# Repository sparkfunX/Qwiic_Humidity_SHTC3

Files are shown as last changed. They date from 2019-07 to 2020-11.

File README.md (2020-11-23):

SparkX Qwiic Humidity SHTC3
========================================

Qwiic_Humidity_SHTC3

[*Qwiic Humidity SHTC3*](https://www.sparkfun.com/products/15074)

<Basic description of the part.>

Repository Contents
-------------------

* **/Documentation** - Data sheets, additional product information
* **/Enclosure** - Enclosure files 
* **/Firmware** - Example code 
* **/Hardware** - Eagle design files (.brd, .sch)
* **/Libraries** - Libraries for use with the <PRODUCT NAME>
* **/Production** - Production panel files (.brd)
* **/Software** - Related software for the <PRODUCT NAME>

Documentation
--------------
* **[Arduino Library](https://github.com/sparkfun/SparkFun_SHTC3_Arduino_Library)** - Arduino Library.
* **[Hookup Guide](https://learn.sparkfun.com/tutorials/sparkfun-humidity-sensor-breakout---shtc3-qwiic-hookup-guide)** - Basic hookup guide for the.
* **[SparkFun Fritzing repo](https://github.com/sparkfun/Fritzing_Parts)** - Fritzing diagrams for SparkFun products.
* **[SparkFun 3D Model repo](https://github.com/sparkfun/3D_Models)** - 3D models of SparkFun products. 
* **[SparkFun Graphical Datasheets](https://github.com/sparkfun/Graphical_Datasheets)** -Graphical Datasheets for various SparkFun products.

Product Versions
----------------
* [Part SKU](part URL)- Basic part and short description here
* [Retail part SKU] (retail URL)- Retail packaging of standard description here
* [Any other parts this repo covers](any other URLs) - Description of said parts

Version History
---------------
* [vExxFxxZxxHxxLxxSxx](URL for tag specific to this version) - Description 
* [vEyyFyyZyyHyyLyySyy](URL for tag specific to this version) - Description

License Information
-------------------

This product is _**open source**_! 

Please review the LICENSE.md file for license information. 

If you have any questions or concerns on licensing, please contact techsupport@sparkfun.com.

Distributed as-is; no warranty is given.

- Your friends at SparkFun.

_<COLLABORATION CREDIT>_

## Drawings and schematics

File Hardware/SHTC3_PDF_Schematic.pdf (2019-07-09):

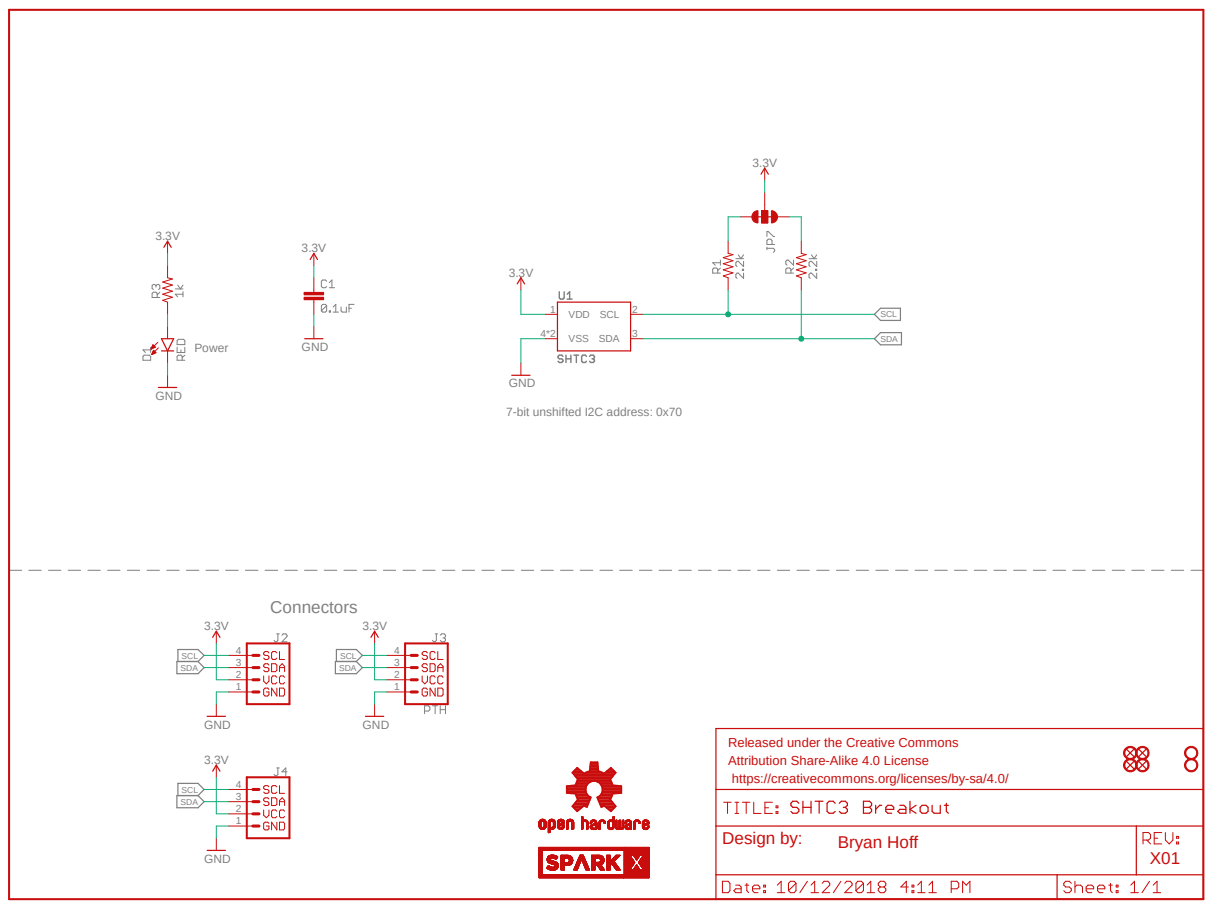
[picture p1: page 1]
Power; Connectors; GND; VDD 1; SCL 2 VSS 4*2; SDA 3; SCL; SCL SCL; SDA; Bryan Hoff; Design by:

7-bit unshifted I2C address: 0x70

Released under the Creative Commons
Attribution Share-Alike 4.0 License
https://creativecommons.org/licenses/by-sa/4.0/

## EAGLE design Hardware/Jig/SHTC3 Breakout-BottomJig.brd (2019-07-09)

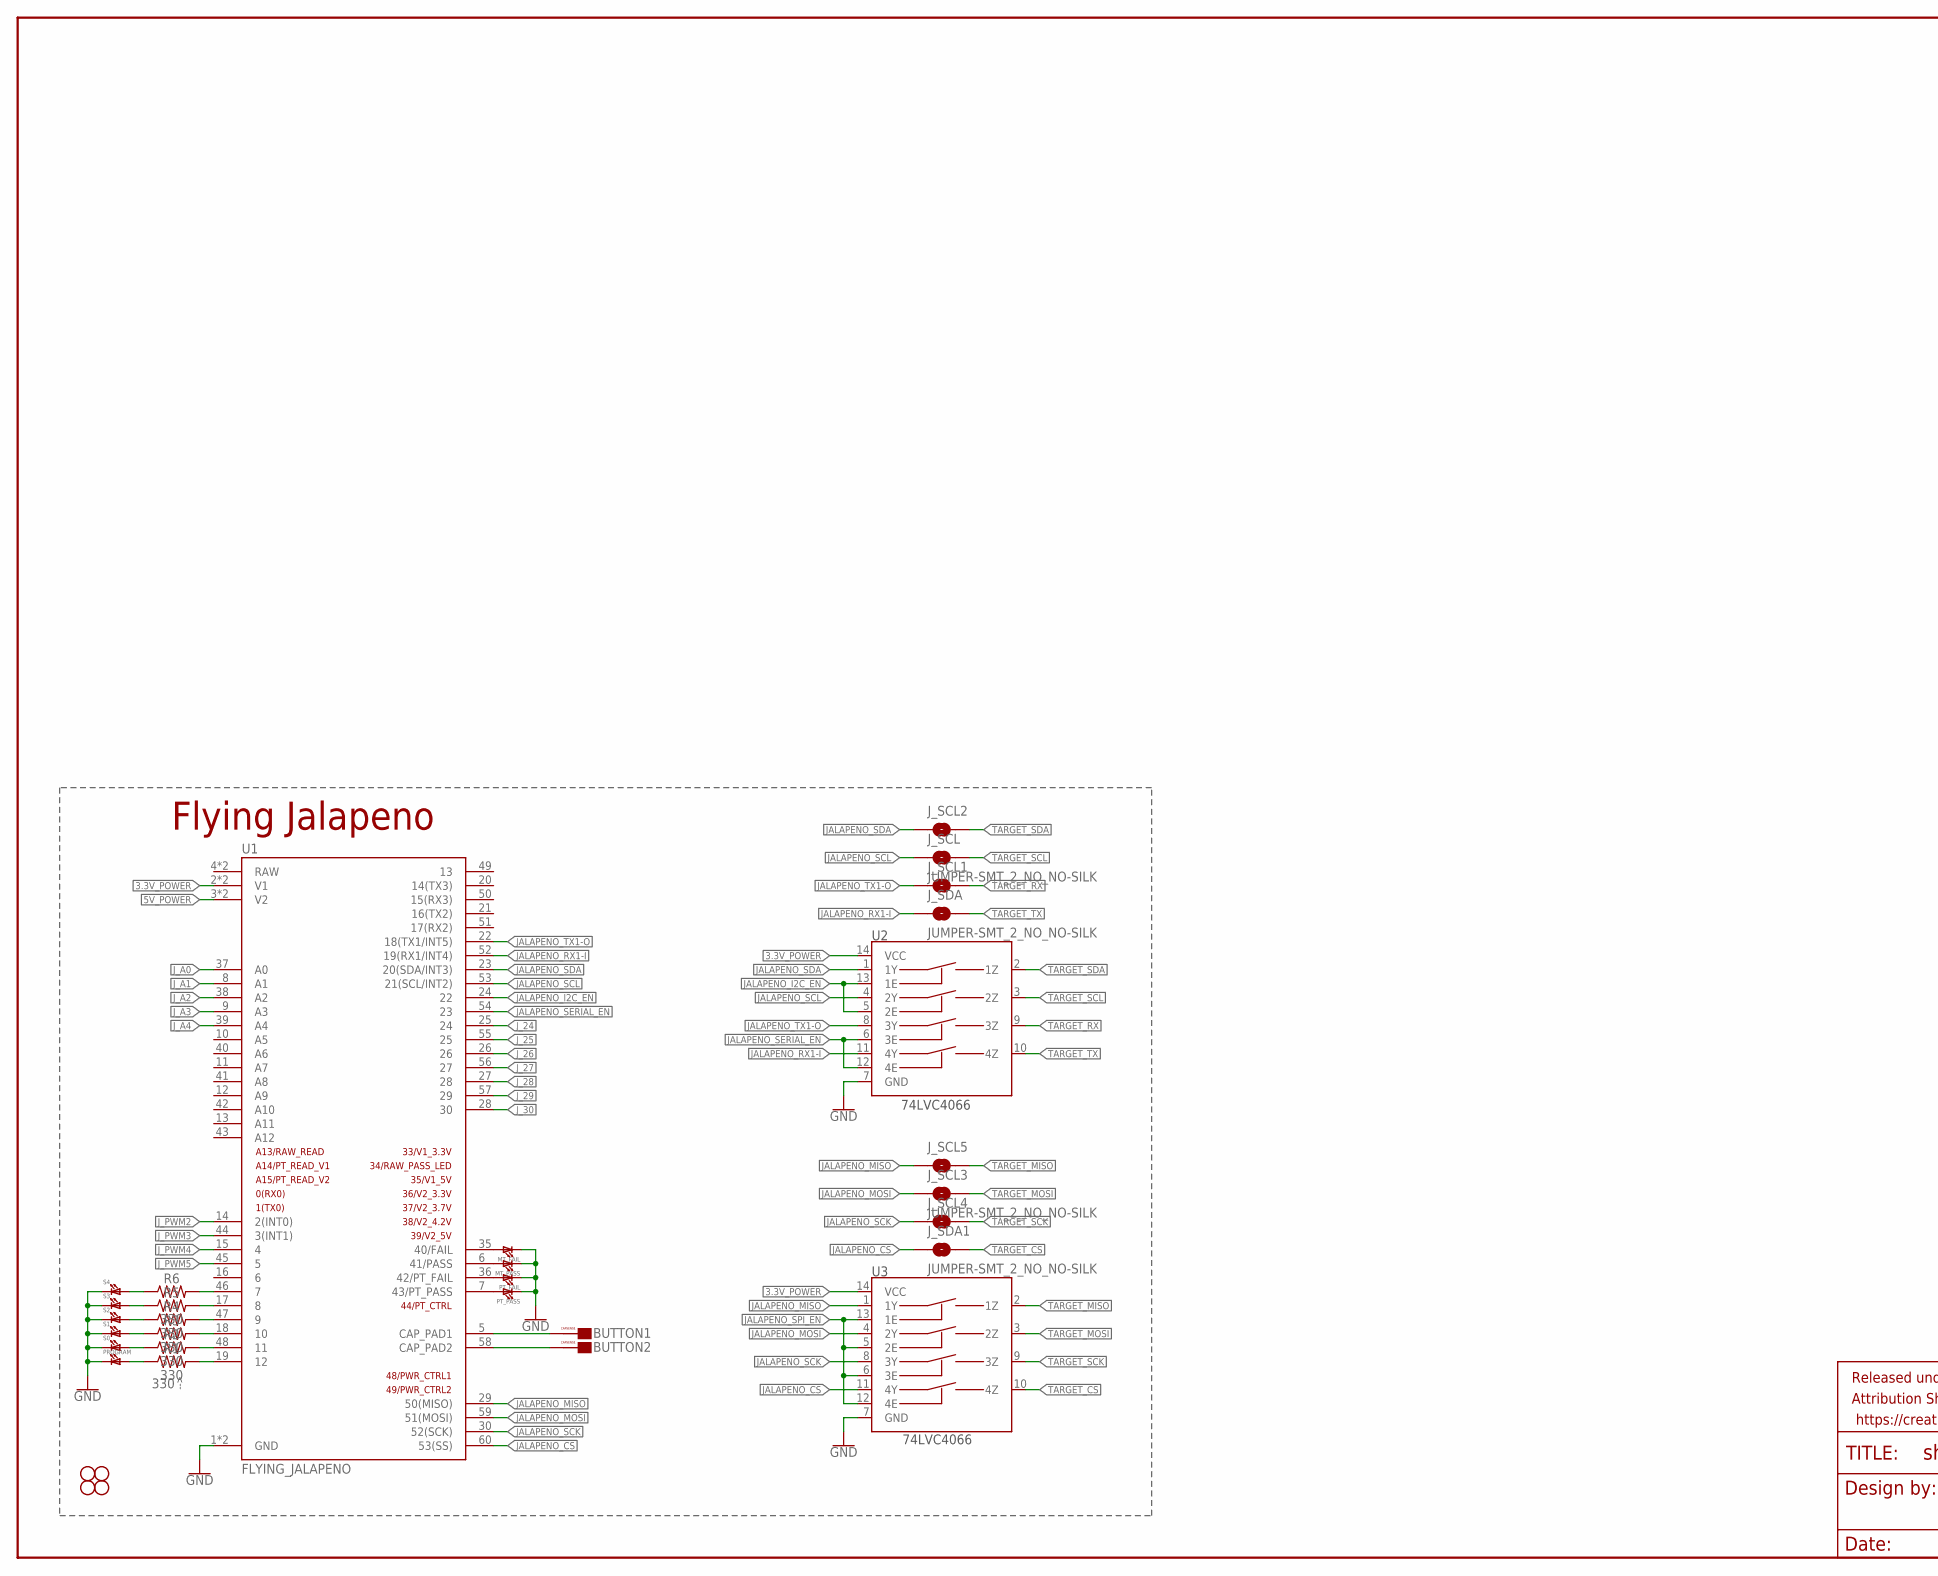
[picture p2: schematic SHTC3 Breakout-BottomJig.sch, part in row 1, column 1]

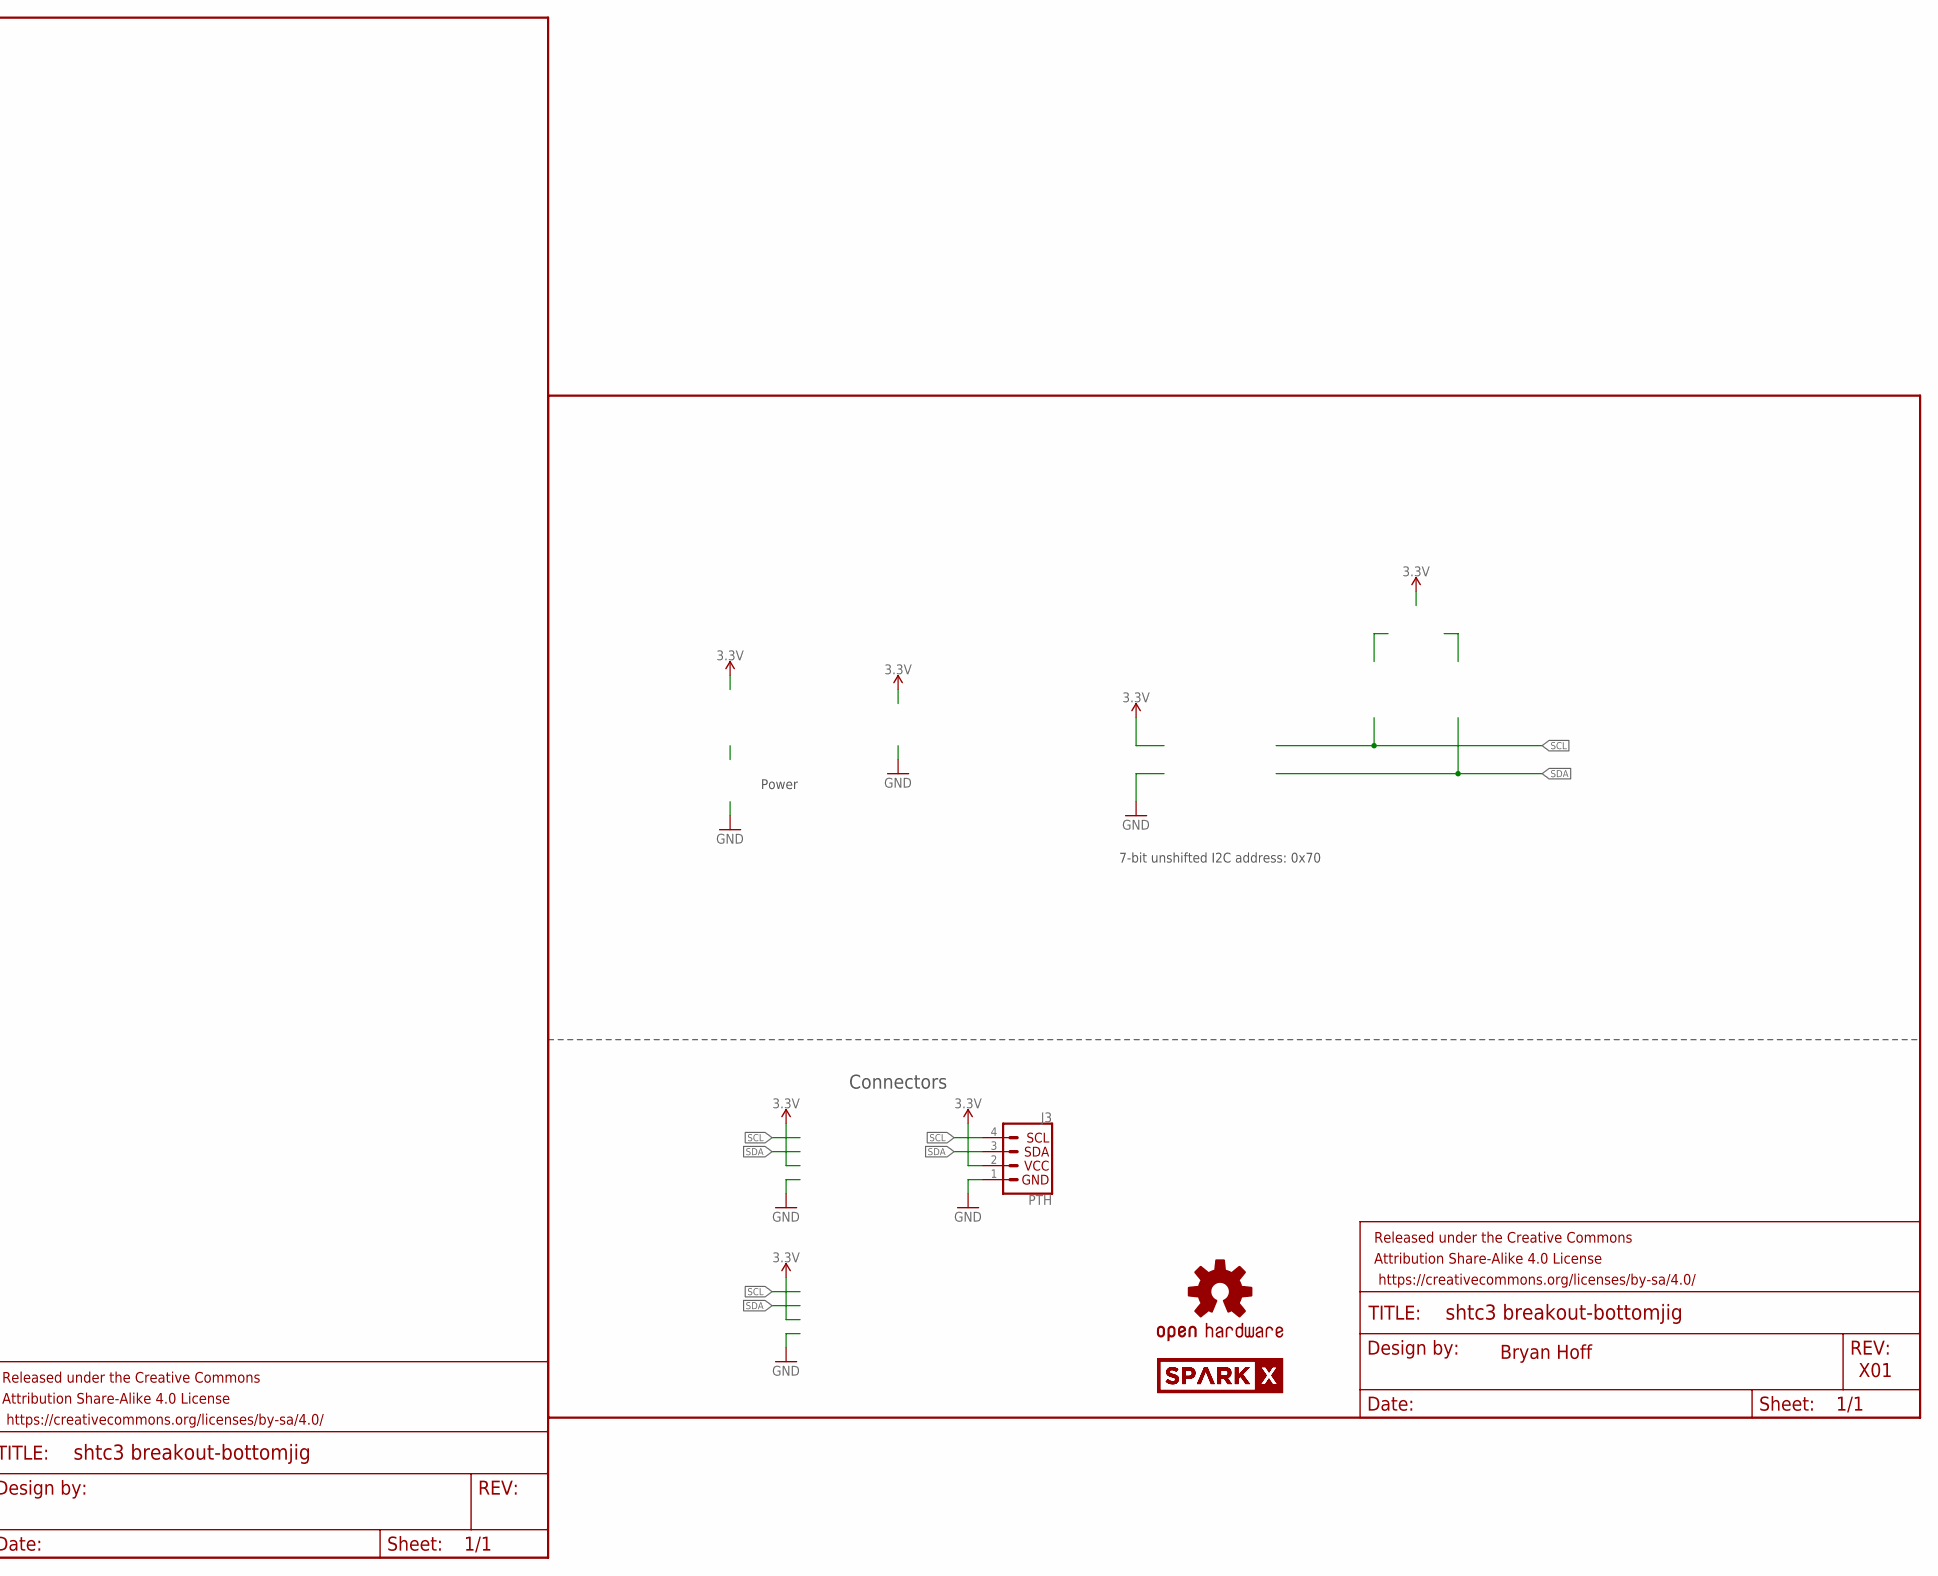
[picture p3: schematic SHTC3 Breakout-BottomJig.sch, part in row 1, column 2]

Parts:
BUTTON1, BUTTON2: CAPSENSE_BUTTON_PAD_ONLY; CAPSENSE_BUTTON_PADS_ONLY
FRAME1: FRAME-LETTER; CREATIVE_COMMONS
FRAME2: FRAME-LEDGER; CREATIVE_COMMONS
H1, H2, H3, H4: STAND-OFF
J3: PTH; 1X04_NO_SILK
J_SCL, J_SCL1, J_SCL2, J_SCL3, J_SCL4, J_SCL5: JUMPER-SMT_2_NO_NO-SILK; SMT-JUMPER_2_NO_NO-SILK
J_SDA, J_SDA1: JUMPER-SMT_2_NO_NO-SILK; SMT-JUMPER_2_NO_NO-SILK
LOGO1: OSHW-LOGOMINI; OSHW-LOGO-MINI
MT_FAIL: LED1206; LED-1206
MT_PASS: LED1206; LED-1206
PROGRAM: LED1206; LED-1206
PT_FAIL: LED1206; LED-1206
PT_PASS: LED1206; LED-1206
R1, R2, R3, R4, R5, R6: 330; 0603
S0, S1, S2, S3, S4: LED1206; LED-1206
U1: FLYING_JALAPENO; FLYING_JALAPENO_V3_M
U2, U3: 74LVC4066; SO14
U$1, U$2: SPARKX-LOGO4; SPARKX-MEDIUM

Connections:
3.3V: J3.2 (VCC)
3.3V_POWER: U1.2 (V1), U1.32 (V1), U2.14 (VCC), U3.14 (VCC)
5V_POWER: U1.3 (V2), U1.33 (V2)
GND: J3.1 (GND), MT_FAIL.C, MT_PASS.C, PROGRAM.C, PT_FAIL.C, PT_PASS.C, S0.C, S1.C, S2.C, S3.C, S4.C, U1.1 (GND), U1.31 (GND), U2.7 (GND), U3.7 (GND)
JALAPENO_CS: J_SDA1.1, U1.60 (53(SS)), U3.11 (4Y)
JALAPENO_I2C_EN: U1.24 (22), U2.5 (2E), U2.13 (1E)
JALAPENO_MISO: J_SCL5.1, U1.29 (50(MISO)), U3.1 (1Y)
JALAPENO_MOSI: J_SCL3.1, U1.59 (51(MOSI)), U3.4 (2Y)
JALAPENO_RX1-I: J_SDA.1, U1.52 (19(RX1/INT4)), U2.11 (4Y)
JALAPENO_SCK: J_SCL4.1, U1.30 (52(SCK)), U3.8 (3Y)
JALAPENO_SCL: J_SCL.1, U1.53 (21(SCL/INT2)), U2.4 (2Y)
JALAPENO_SDA: J_SCL2.1, U1.23 (20(SDA/INT3)), U2.1 (1Y)
JALAPENO_SERIAL_EN: U1.54 (23), U2.6 (3E), U2.12 (4E)
JALAPENO_SPI_EN: U3.5 (2E), U3.6 (3E), U3.12 (4E), U3.13 (1E)
JALAPENO_TX1-O: J_SCL1.1, U1.22 (18(TX1/INT5)), U2.8 (3Y)
J_24: U1.25 (24)
J_25: U1.55 (25)
J_26: U1.26
J_27: U1.56 (27)
J_28: U1.27 (28)
J_29: U1.57 (29)
J_30: U1.28 (30)
J_A0: U1.37 (A0)
J_A1: U1.8 (A1)
J_A2: U1.38 (A2)
J_A3: U1.9 (A3)
J_A4: U1.39 (A4)
J_PWM2: U1.14 (2(INT0))
J_PWM3: U1.44 (3(INT1))
J_PWM4: U1.15 (4)
J_PWM5: U1.45 (5)
unnamed: PT_PASS.A, U1.7 (43/PT_PASS)
unnamed: PT_FAIL.A, U1.36 (42/PT_FAIL)
unnamed: MT_PASS.A, U1.6 (41/PASS)
unnamed: MT_FAIL.A, U1.35 (40/FAIL)
unnamed: BUTTON2.CAPSENSE_PAD, U1.58 (CAP_PAD2)
unnamed: BUTTON1.CAPSENSE_PAD, U1.5 (CAP_PAD1)
unnamed: R6.2, U1.46 (7)
unnamed: R1.2, U1.19 (12)
unnamed: PROGRAM.A, R1.1
unnamed: R5.2, U1.17 (8)
unnamed: R4.2, U1.47 (9)
unnamed: R3.2, U1.18 (10)
unnamed: R2.2, U1.48 (11)
unnamed: R6.1, S4.A
unnamed: R5.1, S3.A
unnamed: R4.1, S2.A
unnamed: R3.1, S1.A
unnamed: R2.1, S0.A
SCL: J3.4 (SCL)
SDA: J3.3 (SDA)
TARGET_CS: J_SDA1.2, U3.10 (4Z)
TARGET_MISO: J_SCL5.2, U3.2 (1Z)
TARGET_MOSI: J_SCL3.2, U3.3 (2Z)
TARGET_RX: J_SCL1.2, U2.9 (3Z)
TARGET_SCK: J_SCL4.2, U3.9 (3Z)
TARGET_SCL: J_SCL.2, U2.3 (2Z)
TARGET_SDA: J_SCL2.2, U2.2 (1Z)
TARGET_TX: J_SDA.2, U2.10 (4Z)

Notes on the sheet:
Bryan Hoff
X01
7-bit unshifted I2C address: 0x70
Power
Connectors
Flying Jalapeno
-->

Board: 2 copper layers, 58 parts (9 on the bottom side), 40 nets, no tracks yet.

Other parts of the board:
U$3, U$22: GND1
U$4, U$21: 3#3V2
U$5, U$27: SDA8
U$6, U$26: SCL9
U$7, U$8: SHTC3_HUMIDITY1
U$9: I_SUPER2_C-()-03
U$10: (PWR)
U$11, U$12, U$13, U$14, U$15, U$16: STAND-OFF-TIGHT
U$29: QWIIC-LOGO-MEDIUM

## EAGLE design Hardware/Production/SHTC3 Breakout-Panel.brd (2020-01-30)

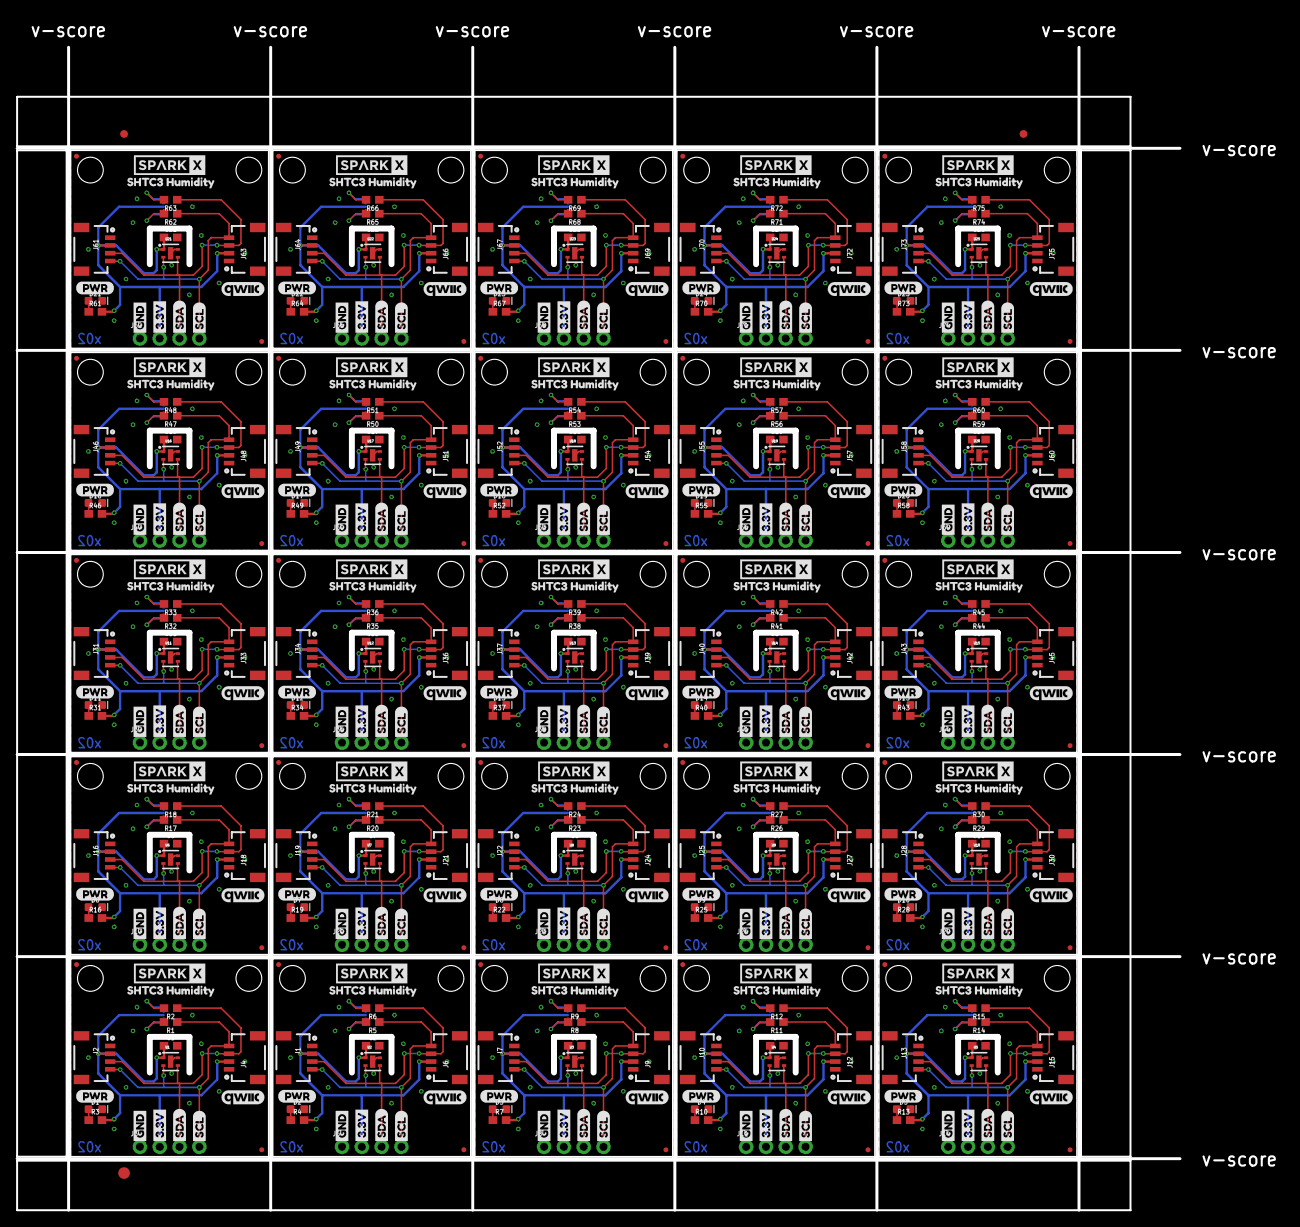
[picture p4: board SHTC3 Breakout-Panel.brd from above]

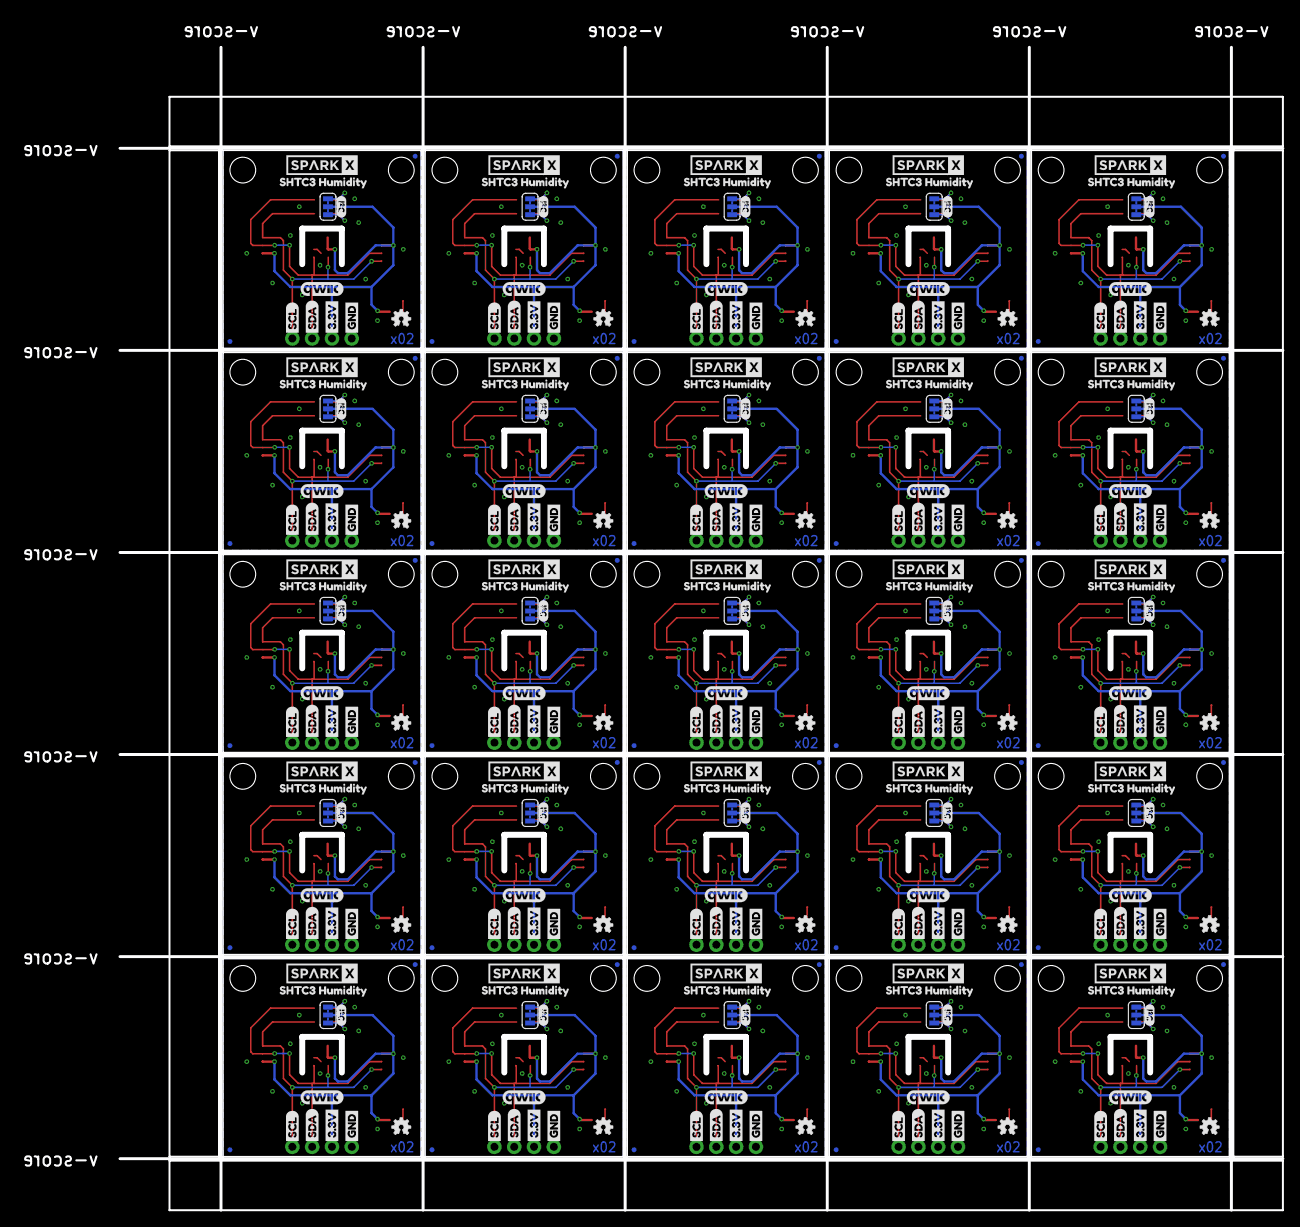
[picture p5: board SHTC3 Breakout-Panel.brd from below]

Board: 2 copper layers, 149.1 x 149.1 mm, 828 parts (300 on the bottom side), 175 nets.

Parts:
C1, C2, C3, C4, C5, C6, C7, C8, C9, C10, C11, C12, C13, C14, C15, C16, C17, C18, C19, C20, C21, C22, C23, C24, C25: 0.1uF; 0603
D1, D2, D3, D4, D5, D6, D7, D8, D9, D10, D11, D12, D13, D14, D15, D16, D17, D18, D19, D20, D21, D22, D23, D24, D25: RED; LED-0603
E$1, E$2: FIDUCIAL-1X2
E$3: FIDUCIAL-1.5X3
J1, J2, J4, J6, J7, J9, J10, J12, J13, J15, J16, J18, J19, J21, J22, J24, J25, J27, J28, J30, J31, J33, J34, J36, J37, J39, J40, J42, J43, J45, J46, J48, J49, J51, J52, J54, J55, J57, J58, J60, J61, J63, J64, J66, J67, J69, J70, J72, J73, J75: 1X04_1MM_RA
J3, J5, J8, J11, J14, J17, J20, J23, J26, J29, J32, J35, J38, J41, J44, J47, J50, J53, J56, J59, J62, J65, J68, J71, J74: PTH; 1X04_NO_SILK
JP1, JP2, JP5, JP6, JP10, JP11, JP12, JP13, JP17, JP18, JP19, JP20, JP24, JP25, JP26, JP27, JP31, JP32, JP33, JP34, JP38, JP39, JP40, JP41, JP45, JP46, JP47, JP48, JP52, JP53, JP54, JP55, JP59, JP60, JP61, JP62, JP66, JP67, JP68, JP69, JP73, JP74, JP75, JP76, JP80, JP81, JP82, JP83, JP87, JP88, JP89, JP90, JP94, JP95, JP96, JP97, JP101, JP102, JP103, JP104, JP108, JP109, JP110, JP111, JP115, JP116, JP117, JP118, JP122, JP123, JP124, JP125, JP129, JP130, JP131, JP132, JP136, JP137, JP138, JP139, JP143, JP144, JP145, JP146, JP150, JP151, JP152, JP153, JP157, JP158, JP159, JP160, JP164, JP165, JP166, JP167, JP171, JP172, JP173, JP174: FIDUCIALUFIDUCIAL; MICRO-FIDUCIAL
JP3, JP4, JP8, JP9, JP15, JP16, JP22, JP23, JP29, JP30, JP36, JP37, JP43, JP44, JP50, JP51, JP57, JP58, JP64, JP65, JP71, JP72, JP78, JP79, JP85, JP86, JP92, JP93, JP99, JP100, JP106, JP107, JP113, JP114, JP120, JP121, JP127, JP128, JP134, JP135, JP141, JP142, JP148, JP149, JP155, JP156, JP162, JP163, JP169, JP170: STAND-OFF
JP7, JP14, JP21, JP28, JP35, JP42, JP49, JP56, JP63, JP70, JP77, JP84, JP91, JP98, JP105, JP112, JP119, JP126, JP133, JP140, JP147, JP154, JP161, JP168, JP175: JUMPER-SMT_3_2-NC_TRACE_SILK; SMT-JUMPER_3_2-NC_TRACE_SILK
LOGO1, LOGO2, LOGO3, LOGO4, LOGO5, LOGO6, LOGO7, LOGO8, LOGO9, LOGO10, LOGO11, LOGO12, LOGO13, LOGO14, LOGO15, LOGO16, LOGO17, LOGO18, LOGO19, LOGO20, LOGO21, LOGO22, LOGO23, LOGO24, LOGO25: OSHW-LOGOMINI; OSHW-LOGO-MINI
R1, R2, R5, R6, R8, R9, R11, R12, R14, R15, R17, R18, R20, R21, R23, R24, R26, R27, R29, R30, R32, R33, R35, R36, R38, R39, R41, R42, R44, R45, R47, R48, R50, R51, R53, R54, R56, R57, R59, R60, R62, R63, R65, R66, R68, R69, R71, R72, R74, R75: 2.2k; 0603
R3, R4, R7, R10, R13, R16, R19, R22, R25, R28, R31, R34, R37, R40, R43, R46, R49, R52, R55, R58, R61, R64, R67, R70, R73: 1k; 0603
U1, U2, U3, U4, U5, U6, U7, U8, U9, U10, U11, U12, U13, U14, U15, U16, U17, U18, U19, U20, U21, U22, U23, U24, U25: SHTC3
U$1, U$2, U$13, U$14, U$33, U$34, U$49, U$50, U$65, U$66, U$81, U$82, U$97, U$98, U$113, U$114, U$129, U$130, U$145, U$146, U$161, U$162, U$177, U$178, U$193, U$194, U$209, U$210, U$225, U$226, U$241, U$242, U$257, U$258, U$273, U$274, U$289, U$290, U$305, U$306, U$321, U$322, U$337, U$338, U$353, U$354, U$369, U$370, U$385, U$386: SPARKX-LOGO4; SPARKX-MEDIUM
U$3, U$16, U$19, U$22, U$36, U$39, U$52, U$55, U$68, U$71, U$84, U$87, U$100, U$103, U$116, U$119, U$132, U$135, U$148, U$151, U$164, U$167, U$180, U$183, U$196, U$199, U$212, U$215, U$228, U$231, U$244, U$247, U$260, U$263, U$276, U$279, U$292, U$295, U$308, U$311, U$324, U$327, U$340, U$343, U$356, U$359, U$372, U$375, U$388, U$391: GND1
U$4, U$15, U$20, U$21, U$35, U$40, U$51, U$56, U$67, U$72, U$83, U$88, U$99, U$104, U$115, U$120, U$131, U$136, U$147, U$152, U$163, U$168, U$179, U$184, U$195, U$200, U$211, U$216, U$227, U$232, U$243, U$248, U$259, U$264, U$275, U$280, U$291, U$296, U$307, U$312, U$323, U$328, U$339, U$344, U$355, U$360, U$371, U$376, U$387, U$392: 3#3V2
U$5, U$18, U$23, U$27, U$38, U$41, U$54, U$57, U$70, U$73, U$86, U$89, U$102, U$105, U$118, U$121, U$134, U$137, U$150, U$153, U$166, U$169, U$182, U$185, U$198, U$201, U$214, U$217, U$230, U$233, U$246, U$249, U$262, U$265, U$278, U$281, U$294, U$297, U$310, U$313, U$326, U$329, U$342, U$345, U$358, U$361, U$374, U$377, U$390, U$393: SDA8
U$6, U$17, U$24, U$26, U$37, U$42, U$53, U$58, U$69, U$74, U$85, U$90, U$101, U$106, U$117, U$122, U$133, U$138, U$149, U$154, U$165, U$170, U$181, U$186, U$197, U$202, U$213, U$218, U$229, U$234, U$245, U$250, U$261, U$266, U$277, U$282, U$293, U$298, U$309, U$314, U$325, U$330, U$341, U$346, U$357, U$362, U$373, U$378, U$389, U$394: SCL9
U$7, U$8, U$28, U$29, U$44, U$45, U$60, U$61, U$76, U$77, U$92, U$93, U$108, U$109, U$124, U$125, U$140, U$141, U$156, U$157, U$172, U$173, U$188, U$189, U$204, U$205, U$220, U$221, U$236, U$237, U$252, U$253, U$268, U$269, U$284, U$285, U$300, U$301, U$316, U$317, U$332, U$333, U$348, U$349, U$364, U$365, U$380, U$381, U$396, U$397: SHTC3_HUMIDITY1
U$9, U$30, U$46, U$62, U$78, U$94, U$110, U$126, U$142, U$158, U$174, U$190, U$206, U$222, U$238, U$254, U$270, U$286, U$302, U$318, U$334, U$350, U$366, U$382, U$398: I_SUPER2_C-()-03
U$10, U$25, U$43, U$59, U$75, U$91, U$107, U$123, U$139, U$155, U$171, U$187, U$203, U$219, U$235, U$251, U$267, U$283, U$299, U$315, U$331, U$347, U$363, U$379, U$395: (PWR)
U$11, U$12, U$31, U$32, U$47, U$48, U$63, U$64, U$79, U$80, U$95, U$96, U$111, U$112, U$127, U$128, U$143, U$144, U$159, U$160, U$175, U$176, U$191, U$192, U$207, U$208, U$223, U$224, U$239, U$240, U$255, U$256, U$271, U$272, U$287, U$288, U$303, U$304, U$319, U$320, U$335, U$336, U$351, U$352, U$367, U$368, U$383, U$384, U$399, U$400: QWIIC_5.5MM

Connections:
3.3V: C1.1, J2.2, J3.2, J4.2, JP7.2, R3.2, U1.1
3.3V1: C2.1, J1.2, J5.2, J6.2, JP14.2, R4.2, U2.1
3.3V2: C3.1, J7.2, J8.2, J9.2, JP21.2, R7.2, U3.1
3.3V3: C4.1, J10.2, J11.2, J12.2, JP28.2, R10.2, U4.1
3.3V4: C5.1, J13.2, J14.2, J15.2, JP35.2, R13.2, U5.1
3.3V5: C6.1, J16.2, J17.2, J18.2, JP42.2, R16.2, U6.1
3.3V6: C7.1, J19.2, J20.2, J21.2, JP49.2, R19.2, U7.1
3.3V7: C8.1, J22.2, J23.2, J24.2, JP56.2, R22.2, U8.1
3.3V8: C9.1, J25.2, J26.2, J27.2, JP63.2, R25.2, U9.1
3.3V9: C10.1, J28.2, J29.2, J30.2, JP70.2, R28.2, U10.1
3.3V10: C11.1, J31.2, J32.2, J33.2, JP77.2, R31.2, U11.1
3.3V11: C12.1, J34.2, J35.2, J36.2, JP84.2, R34.2, U12.1
3.3V12: C13.1, J37.2, J38.2, J39.2, JP91.2, R37.2, U13.1
3.3V13: C14.1, J40.2, J41.2, J42.2, JP98.2, R40.2, U14.1
3.3V14: C15.1, J43.2, J44.2, J45.2, JP105.2, R43.2, U15.1
3.3V15: C16.1, J46.2, J47.2, J48.2, JP112.2, R46.2, U16.1
3.3V16: C17.1, J49.2, J50.2, J51.2, JP119.2, R49.2, U17.1
3.3V17: C18.1, J52.2, J53.2, J54.2, JP126.2, R52.2, U18.1
3.3V18: C19.1, J55.2, J56.2, J57.2, JP133.2, R55.2, U19.1
3.3V19: C20.1, J58.2, J59.2, J60.2, JP140.2, R58.2, U20.1
3.3V20: C21.1, J61.2, J62.2, J63.2, JP147.2, R61.2, U21.1
3.3V21: C22.1, J64.2, J65.2, J66.2, JP154.2, R64.2, U22.1
3.3V22: C23.1, J67.2, J68.2, J69.2, JP161.2, R67.2, U23.1
3.3V23: C24.1, J70.2, J71.2, J72.2, JP168.2, R70.2, U24.1
3.3V24: C25.1, J73.2, J74.2, J75.2, JP175.2, R73.2, U25.1
GND: C1.2, D1.C, J2.1, J3.1, J4.1, U1.4, U1.5
GND1: C2.2, D2.C, J1.1, J5.1, J6.1, U2.4, U2.5
GND2: C3.2, D3.C, J7.1, J8.1, J9.1, U3.4, U3.5
GND3: C4.2, D4.C, J10.1, J11.1, J12.1, U4.4, U4.5
GND4: C5.2, D5.C, J13.1, J14.1, J15.1, U5.4, U5.5
GND5: C6.2, D6.C, J16.1, J17.1, J18.1, U6.4, U6.5
GND6: C7.2, D7.C, J19.1, J20.1, J21.1, U7.4, U7.5
GND7: C8.2, D8.C, J22.1, J23.1, J24.1, U8.4, U8.5
GND8: C9.2, D9.C, J25.1, J26.1, J27.1, U9.4, U9.5
GND9: C10.2, D10.C, J28.1, J29.1, J30.1, U10.4, U10.5
GND10: C11.2, D11.C, J31.1, J32.1, J33.1, U11.4, U11.5
GND11: C12.2, D12.C, J34.1, J35.1, J36.1, U12.4, U12.5
GND12: C13.2, D13.C, J37.1, J38.1, J39.1, U13.4, U13.5
GND13: C14.2, D14.C, J40.1, J41.1, J42.1, U14.4, U14.5
GND14: C15.2, D15.C, J43.1, J44.1, J45.1, U15.4, U15.5
GND15: C16.2, D16.C, J46.1, J47.1, J48.1, U16.4, U16.5
GND16: C17.2, D17.C, J49.1, J50.1, J51.1, U17.4, U17.5
GND17: C18.2, D18.C, J52.1, J53.1, J54.1, U18.4, U18.5
GND18: C19.2, D19.C, J55.1, J56.1, J57.1, U19.4, U19.5
GND19: C20.2, D20.C, J58.1, J59.1, J60.1, U20.4, U20.5
GND20: C21.2, D21.C, J61.1, J62.1, J63.1, U21.4, U21.5
GND21: C22.2, D22.C, J64.1, J65.1, J66.1, U22.4, U22.5
GND22: C23.2, D23.C, J67.1, J68.1, J69.1, U23.4, U23.5
GND23: C24.2, D24.C, J70.1, J71.1, J72.1, U24.4, U24.5
GND24: C25.2, D25.C, J73.1, J74.1, J75.1, U25.4, U25.5
unnamed: JP7.3, R1.2
unnamed: JP7.1, R2.2
unnamed: D1.A, R3.1
unnamed: D2.A, R4.1
unnamed: JP14.3, R5.2
unnamed: JP14.1, R6.2
unnamed: D3.A, R7.1
unnamed: JP21.3, R8.2
unnamed: JP21.1, R9.2
unnamed: D4.A, R10.1
unnamed: JP28.3, R11.2
unnamed: JP28.1, R12.2
unnamed: D5.A, R13.1
unnamed: JP35.3, R14.2
unnamed: JP35.1, R15.2
unnamed: D6.A, R16.1
unnamed: JP42.3, R17.2
unnamed: JP42.1, R18.2
unnamed: D7.A, R19.1
unnamed: JP49.3, R20.2
unnamed: JP49.1, R21.2
unnamed: D8.A, R22.1
unnamed: JP56.3, R23.2
unnamed: JP56.1, R24.2
unnamed: D9.A, R25.1
unnamed: JP63.3, R26.2
unnamed: JP63.1, R27.2
unnamed: D10.A, R28.1
unnamed: JP70.3, R29.2
unnamed: JP70.1, R30.2
unnamed: D11.A, R31.1
unnamed: JP77.3, R32.2
unnamed: JP77.1, R33.2
unnamed: D12.A, R34.1
unnamed: JP84.3, R35.2
unnamed: JP84.1, R36.2
unnamed: D13.A, R37.1
unnamed: JP91.3, R38.2
unnamed: JP91.1, R39.2
unnamed: D14.A, R40.1
unnamed: JP98.3, R41.2
unnamed: JP98.1, R42.2
unnamed: D15.A, R43.1
unnamed: JP105.3, R44.2
unnamed: JP105.1, R45.2
unnamed: D16.A, R46.1
unnamed: JP112.3, R47.2
unnamed: JP112.1, R48.2
unnamed: D17.A, R49.1
unnamed: JP119.3, R50.2
unnamed: JP119.1, R51.2
unnamed: D18.A, R52.1
unnamed: JP126.3, R53.2
unnamed: JP126.1, R54.2
unnamed: D19.A, R55.1
unnamed: JP133.3, R56.2
unnamed: JP133.1, R57.2
unnamed: D20.A, R58.1
unnamed: JP140.3, R59.2
unnamed: JP140.1, R60.2
unnamed: D21.A, R61.1
unnamed: JP147.3, R62.2
unnamed: JP147.1, R63.2
unnamed: D22.A, R64.1
unnamed: JP154.3, R65.2
unnamed: JP154.1, R66.2
unnamed: D23.A, R67.1
unnamed: JP161.3, R68.2
unnamed: JP161.1, R69.2
unnamed: D24.A, R70.1
unnamed: JP168.3, R71.2
unnamed: JP168.1, R72.2
unnamed: D25.A, R73.1
unnamed: JP175.3, R74.2
unnamed: JP175.1, R75.2
SCL: J2.4, J3.4, J4.4, R1.1, U1.2
SCL1: J1.4, J5.4, J6.4, R5.1, U2.2
SCL2: J7.4, J8.4, J9.4, R8.1, U3.2
SCL3: J10.4, J11.4, J12.4, R11.1, U4.2
SCL4: J13.4, J14.4, J15.4, R14.1, U5.2
SCL5: J16.4, J17.4, J18.4, R17.1, U6.2
SCL6: J19.4, J20.4, J21.4, R20.1, U7.2
SCL7: J22.4, J23.4, J24.4, R23.1, U8.2
SCL8: J25.4, J26.4, J27.4, R26.1, U9.2
SCL9: J28.4, J29.4, J30.4, R29.1, U10.2
SCL10: J31.4, J32.4, J33.4, R32.1, U11.2
SCL11: J34.4, J35.4, J36.4, R35.1, U12.2
SCL12: J37.4, J38.4, J39.4, R38.1, U13.2
SCL13: J40.4, J41.4, J42.4, R41.1, U14.2
SCL14: J43.4, J44.4, J45.4, R44.1, U15.2
SCL15: J46.4, J47.4, J48.4, R47.1, U16.2
SCL16: J49.4, J50.4, J51.4, R50.1, U17.2
SCL17: J52.4, J53.4, J54.4, R53.1, U18.2
SCL18: J55.4, J56.4, J57.4, R56.1, U19.2
SCL19: J58.4, J59.4, J60.4, R59.1, U20.2
SCL20: J61.4, J62.4, J63.4, R62.1, U21.2
SCL21: J64.4, J65.4, J66.4, R65.1, U22.2
SCL22: J67.4, J68.4, J69.4, R68.1, U23.2
SCL23: J70.4, J71.4, J72.4, R71.1, U24.2
SCL24: J73.4, J74.4, J75.4, R74.1, U25.2
SDA: J2.3, J3.3, J4.3, R2.1, U1.3
SDA1: J1.3, J5.3, J6.3, R6.1, U2.3
SDA2: J7.3, J8.3, J9.3, R9.1, U3.3
SDA3: J10.3, J11.3, J12.3, R12.1, U4.3
SDA4: J13.3, J14.3, J15.3, R15.1, U5.3
SDA5: J16.3, J17.3, J18.3, R18.1, U6.3
SDA6: J19.3, J20.3, J21.3, R21.1, U7.3
SDA7: J22.3, J23.3, J24.3, R24.1, U8.3
SDA8: J25.3, J26.3, J27.3, R27.1, U9.3
SDA9: J28.3, J29.3, J30.3, R30.1, U10.3
SDA10: J31.3, J32.3, J33.3, R33.1, U11.3
SDA11: J34.3, J35.3, J36.3, R36.1, U12.3
SDA12: J37.3, J38.3, J39.3, R39.1, U13.3
SDA13: J40.3, J41.3, J42.3, R42.1, U14.3
SDA14: J43.3, J44.3, J45.3, R45.1, U15.3
SDA15: J46.3, J47.3, J48.3, R48.1, U16.3
SDA16: J49.3, J50.3, J51.3, R51.1, U17.3
SDA17: J52.3, J53.3, J54.3, R54.1, U18.3
SDA18: J55.3, J56.3, J57.3, R57.1, U19.3
SDA19: J58.3, J59.3, J60.3, R60.1, U20.3
SDA20: J61.3, J62.3, J63.3, R63.1, U21.3
SDA21: J64.3, J65.3, J66.3, R66.1, U22.3
SDA22: J67.3, J68.3, J69.3, R69.1, U23.3
SDA23: J70.3, J71.3, J72.3, R72.1, U24.3
SDA24: J73.3, J74.3, J75.3, R75.1, U25.3

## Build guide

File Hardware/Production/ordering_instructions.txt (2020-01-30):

panel size, 143x143mm
PCB thickness, 1.6mm
number of layers, 2
soldermask color, Black
silkscreen color, White
oz copper, 1oz
finish, HASL lead free
stencils, top+bottom
pcs per panel, 25
min trace width, 0.2032mm / 0.0080in
min drill size, 0.3048mm / 0.0120in

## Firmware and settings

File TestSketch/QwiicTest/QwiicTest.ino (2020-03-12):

/*

*/

#include "SparkFun_SHTC3.h" // Click here to get the library: http://librarymanager/All#SparkFun_SHTC3

SHTC3 mySHTC3;

const byte statLED = 13;

void setup() {
  Serial.begin(115200);
  Serial.println("SHTC3 Tester");

  pinMode(statLED, OUTPUT);
  digitalWrite(statLED, LOW);
}

void loop() {
  if (mySHTC3.begin() == SHTC3_Status_Nominal)
  {
    while (mySHTC3.lastStatus == SHTC3_Status_Nominal)
    {
      mySHTC3.update();
      Serial.print("RH = ");
      Serial.print(mySHTC3.toPercent());
      Serial.println();

      if(mySHTC3.toPercent() > 1.0 && mySHTC3.toPercent() < 99.0)
      {
        digitalWrite(statLED, HIGH); //Indicate good board        
      }

      delay(50);
    }
  }
  else
  {
    Serial.println("No sensor detected");
    digitalWrite(statLED, LOW);
  }

  delay(100);
}

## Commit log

2018-10-11 Initial Commit
    SHTC3 Sensor
2018-10-11 Created PCB footprint
2018-10-12 Commit before Blacks
    [SHTC3 Breakout-Panel.brd, SHTC3 Breakout.brd, SHTC3 Breakout.sch]
2019-07-09 Correcting HW Version
    Looks like release version wasn't commited. Updating.
    [SHTC3 Breakout-BottomJig.brd, SHTC3 Breakout-BottomJig.sch, SHTC3 Breakout-MiddleJig.brd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]
2019-12-11 Remove extra/empty files
    [SHTC3 Breakout.brd, SHTC3 Breakout.sch]
2020-01-30 Decrease via size. Change Qwiic logo.
    [SHTC3 Breakout.brd]
2020-01-30 Update production files
    [SHTC3 Breakout-Panel.GBL, SHTC3 Breakout-Panel.GBO, SHTC3 Breakout-Panel.GBS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]

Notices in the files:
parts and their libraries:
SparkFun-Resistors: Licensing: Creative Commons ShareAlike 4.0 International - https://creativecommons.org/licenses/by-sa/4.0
